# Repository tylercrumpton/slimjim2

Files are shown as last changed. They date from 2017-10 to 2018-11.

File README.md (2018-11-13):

# slimjim2

**slimjim2** is a multi-purpose adapter board for RF form-factor Synapse Wireless SNAP modules like the RF100 and RF200.
The original [slimjim] supported a custom module dubbed the TC200, but the **slimjim2** drops support for it in favor of
a ton of cool features. All pins are broken out to a set of standard 0.1" (2.54 mm) headers for jumper cables,
breadboarding, or soldering.



## Features
**slimjim2** contains a few features that make using RF-style SNAP devices in one-off or development projects easier:

- 0.1" (2.54 mm) pin header breakout for all pins
- Silkscreen marks for pins
- Optionally-populated functionality:
  - 3.3V regulator capable of handling input voltages of up tp 15V
  - CH430 USB<->UART adapter for SNAP bridge applications
  - Auto-reset on DTR (for SNAP bridge applications)
  - Reset pushbutton
  - 6-pin serial header
  - Backfeed protection diode for USB power
- USB Type-C port can be used for serial data and power (if regulator and USB<->UART populated)
- 3mm mounting hole
- Module orientation marker
- Open-source hardware designs

## Specifications:
- Dimensions: 1.9" x 1.4" (48.26mm x 35.56mm)

## Supported boards
The following modules should work in the **slimjim2**:

- RF100
- RF200
- RF220
- RF300

## Versions

### v2.1

 
- USB Type-C connector
- Backfeed protection diode for USB power
- Flat reset button (not side-mounted)
 
### v2.0
 
- MicroUSB connector
- Side-mounted reset button

[slimjim]: https://github.com/tylercrumpton/slimjim

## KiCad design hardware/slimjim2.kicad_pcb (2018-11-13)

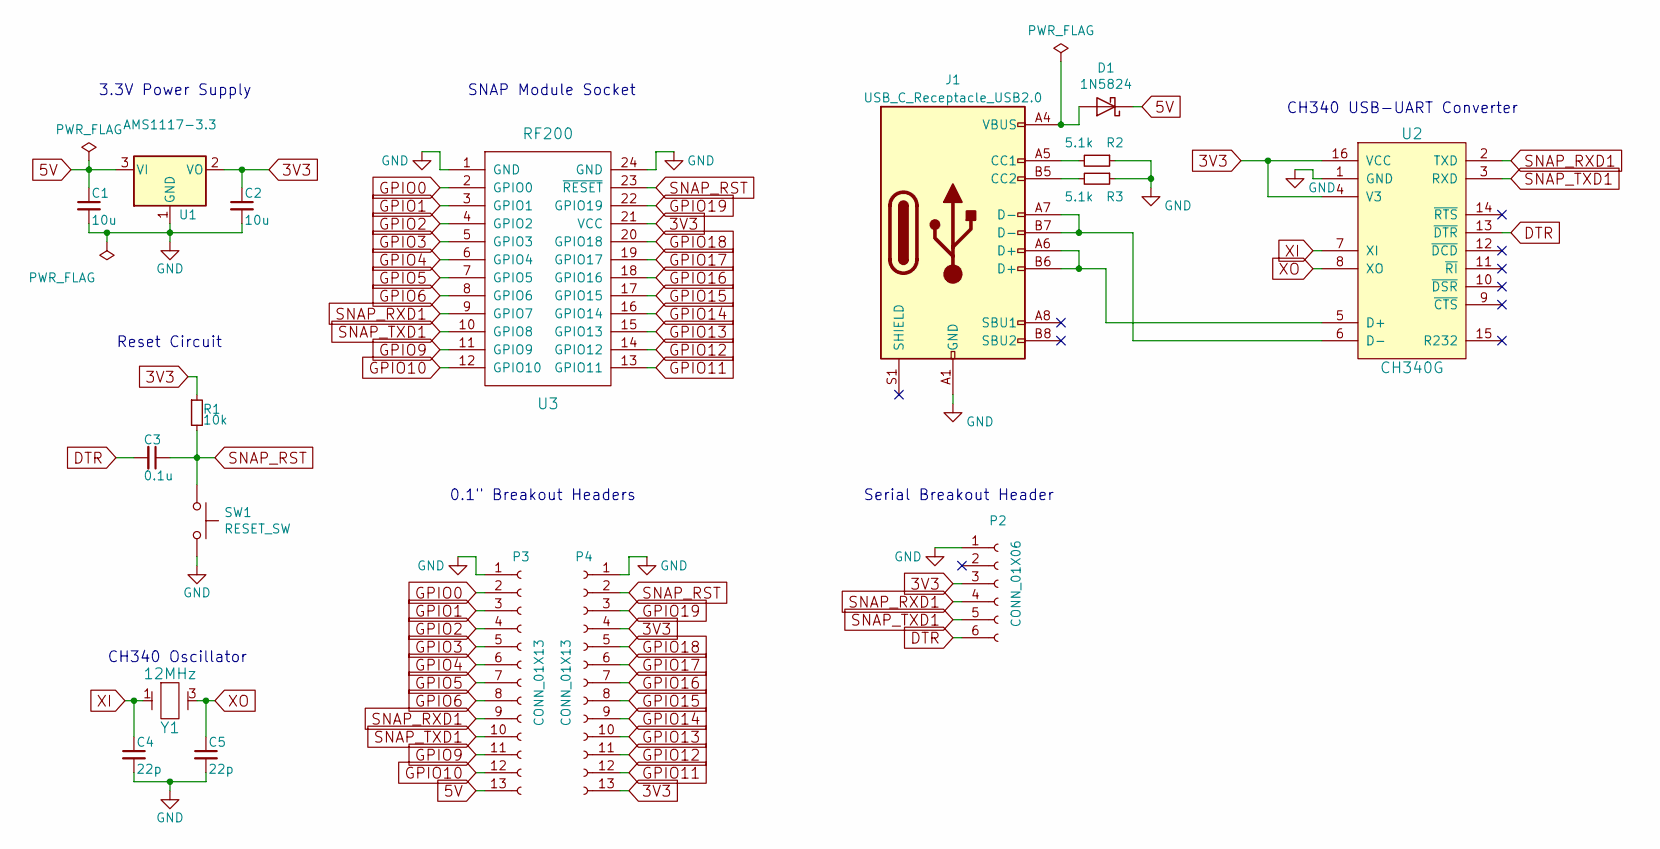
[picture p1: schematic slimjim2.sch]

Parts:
C1, C2: 10u; C_0805_HandSoldering
C3: 0.1u; C_0805_HandSoldering
C4, C5: 22p; C_0805_HandSoldering
D1: 1N5824; D_SMB
J1: USB_C_Receptacle_USB2.0; USB_C_Receptacle_SMD_THT
P2: CONN_01X06; Pin_Header_Straight_1x06_Pitch2.54mm
P3, P4: CONN_01X13; Pin_Header_Straight_1x13_Pitch2.54mm
R1: 10k; R_0805_HandSoldering
R2, R3: 5.1k; R_0805_HandSoldering
SW1: RESET_SW; SW_PUSH_6mm_h4.3mm
U1: AMS1117-3.3; SOT-223
U2: CH340G; SO-16-N
U3: RF200
Y1: 12MHz; Crystal_SMD_3225-4pin_3.2x2.5mm_HandSoldering

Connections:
3V3: C2.1, P2.3, P4.4, P4.13, R1.1, U1.2 (VO), U2.4 (V3), U2.16 (VCC), U3.21 (VCC)
5V: C1.1, D1.1 (K), P3.13, U1.3 (VI)
DTR: C3.2, P2.6, U2.13 (~DTR)
GND: C1.2, C2.2, C4.2, C5.2, J1.A1 (GND), J1.A12 (GND), J1.B1 (GND), J1.B12 (GND), P2.1, P3.1, P4.1, R2.1, R3.1, SW1.2, U1.1 (GND), U2.1 (GND), U3.1 (GND), U3.24 (GND); also elsewhere on the board
GPIO0: P3.2, U3.2 (GPIO0)
GPIO1: P3.3, U3.3 (GPIO1)
GPIO2: P3.4, U3.4 (GPIO2)
GPIO3: P3.5, U3.5 (GPIO3)
GPIO4: P3.6, U3.6 (GPIO4)
GPIO5: P3.7, U3.7 (GPIO5)
GPIO6: P3.8, U3.8 (GPIO6)
GPIO9: P3.11, U3.11 (GPIO9)
GPIO10: P3.12, U3.12 (GPIO10)
GPIO11: P4.12, U3.13 (GPIO11)
GPIO12: P4.11, U3.14 (GPIO12)
GPIO13: P4.10, U3.15 (GPIO13)
GPIO14: P4.9, U3.16 (GPIO14)
GPIO15: P4.8, U3.17 (GPIO15)
GPIO16: P4.7, U3.18 (GPIO16)
GPIO17: P4.6, U3.19 (GPIO17)
GPIO18: P4.5, U3.20 (GPIO18)
GPIO19: P4.3, U3.22 (GPIO19)
unnamed: D1.2 (A), J1.A4 (VBUS), J1.A9 (VBUS), J1.B4 (VBUS), J1.B9 (VBUS)
unnamed: J1.A5 (CC1), R2.2
unnamed: J1.A6 (D+), J1.B6 (D+), U2.5 (D+)
unnamed: J1.A7 (D-), J1.B7 (D-), U2.6 (D-)
unnamed: J1.B5 (CC2), R3.2
SNAP_RST: C3.1, P4.2, R1.2, SW1.1, U3.23 (~RESET); also elsewhere on the board
SNAP_RXD1: P2.4, P3.9, U2.2 (TXD), U3.9 (GPIO7)
SNAP_TXD1: P2.5, P3.10, U2.3 (RXD), U3.10 (GPIO8)
XI: C4.1, U2.7 (XI), Y1.1
XO: C5.1, U2.8 (XO), Y1.3

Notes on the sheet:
CH340 Oscillator
3.3V Power Supply
CH340 USB-UART Converter
Reset Circuit
SNAP Module Socket
0.1" Breakout Headers
Serial Breakout Header

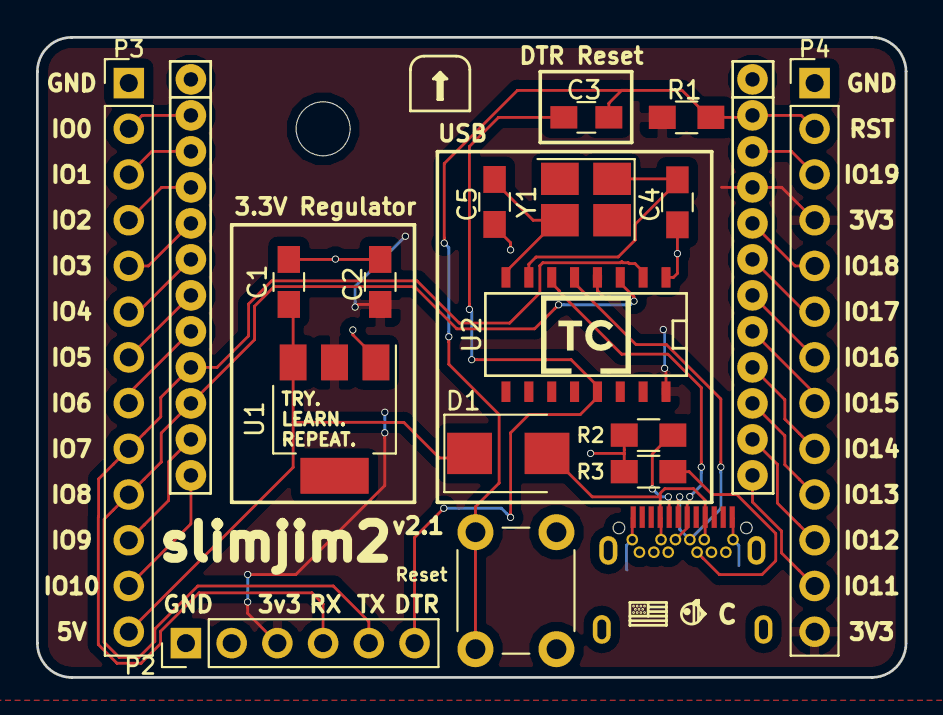
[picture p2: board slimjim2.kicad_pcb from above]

Board: 2 copper layers, 48.3 x 35.6 mm, 19 parts (0 on the bottom side), 32 nets.

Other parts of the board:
Reset: RESET_SW; SW_PUSH_6mm_h4.3mm
svg2mod: G***; tc_30mm

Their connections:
GND: Reset.2; also elsewhere on the board
SNAP_RST: Reset.1; also elsewhere on the board

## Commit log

2017-09-21 Set up initial project structure for sb_ch340g.
    [sb_ch340g.kicad_pcb, sb_ch340g.sch]
2017-09-22 Schematic capture and basic board layout.
    [sb_ch340g.kicad_pcb, sb_ch340g.sch]
2017-09-24 Cleanup layout.
    [sb_ch340g.kicad_pcb, sb_ch340g.sch]
2017-09-24 First pass at routing.
    [sb_ch340g.kicad_pcb]
2017-10-03 Move everything to reflect snapcap name.
    [snapcap.kicad_pcb, snapcap.sch]
2017-10-03 Start adding silk.
    [snapcap.kicad_pcb]
2017-10-05 Finish up silk.
    [slimjim2.kicad_pcb, slimjim2.sch, snapcap.sch]
2017-10-11 Add output settings.
    [slimjim2.kicad_pcb]
2018-11-09 Update for KiCad5.
    [slimjim2.kicad_pcb, slimjim2.sch]
2018-11-12 Update PCB with USB-C part.
    [_saved_slimjim2.sch, slimjim2.kicad_pcb]
2018-11-12 Final board cleanup.
    [_saved_slimjim2.sch, slimjim2.kicad_pcb, slimjim2.sch]
2018-11-13 Update version info.
    [slimjim2.kicad_pcb]

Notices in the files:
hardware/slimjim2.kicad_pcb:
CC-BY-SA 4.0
